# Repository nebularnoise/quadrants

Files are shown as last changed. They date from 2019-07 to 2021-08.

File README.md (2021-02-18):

# Quadrants

Quadrants is a skiff-friendly SMD version of the [Prok Drum Modules](https://www.thonk.co.uk/product-category/manufacturer/prok-modular/).

I love the Prok modules, but the 3-boards sandwich made them too deep to fit in my drum skiff. With this version, the depth is no longer about 40mm, but rather 30mm.

# License

This work is licensed under CC-by-SA 3.0.

It is an adaptation of [Prok-Drums-Hardware](https://github.com/Normalised/Prok-Drums-Hardware), CC-by-SA 3.0 Martin Wood-Mitrovski, a.k.a [@Normalised](https://github.com/Normalised).
Prok Drums is itself an adaptation of [Radio Music](https://github.com/TomWhitwell/RadioMusic), CC-by-SA 3.0 Tom Whitwell, a.k.a. [Music Thing Modular](https://musicthing.co.uk/).

To quote the official Prok Drums page:
> Prok Drums are open hardware, they are a modified version of the Music Thing Modular Radio Music module by Tom Whitwell and have the Creative Commons license CC-BY-SA: Attribution / ShareAlike. If you use any work from this hardware, you should credit Tom Whitwell, and you must republish any changes you make under the same license. The Prok Drums Eagle PCB projects are available under the creative commons license here – [Github Link](https://github.com/Normalised/Prok-Drums-Hardware)

The Quadrants panel uses pictograms derived from the Mutable Instruments Plaits module, licensed under CC-by-SA 3.0. As such, the panel is also licensed under CC-by-SA 3.0.

# Submodule credits
- [4ms/4ms-kicad-lib](https://github.com/4ms/4ms-kicad-lib): Used for some component footprints
  - Thonkiconns
  - Yamaichi SD card holder
  - Alpha 9mm pots
  - rail mounting hole
- [XenGi/teensy.pretty](github.com/XenGi/teensy.pretty): used as inspiration for teensy footprint
- [XenGi/teensy_library](github.com/XenGi/teensy_library): used as inspiration for teensy symbol

# Graphics credit
- Clap icon by [Chathura Kudahetti, LK](https://thenounproject.com/chathura/), released under Public Domain license
- Other pictograms are derived from the Mutable Instruments Plaits module, licensed under CC-by-SA 3.0

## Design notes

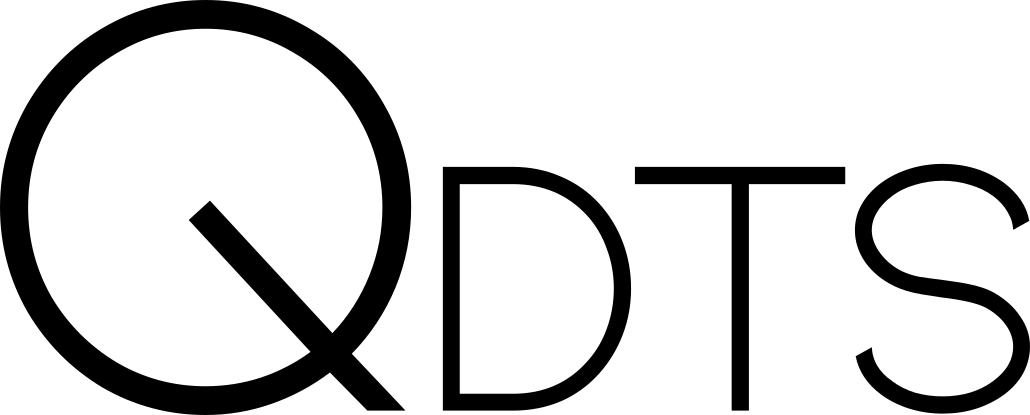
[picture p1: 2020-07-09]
panel_1/qdrnts.png

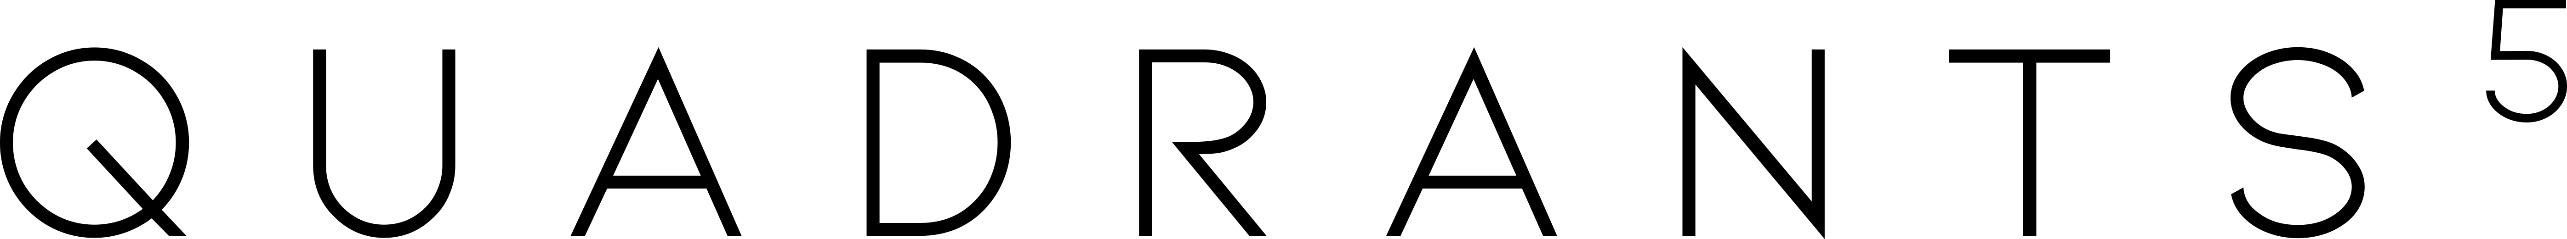
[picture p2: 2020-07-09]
panel_5/panel5.png

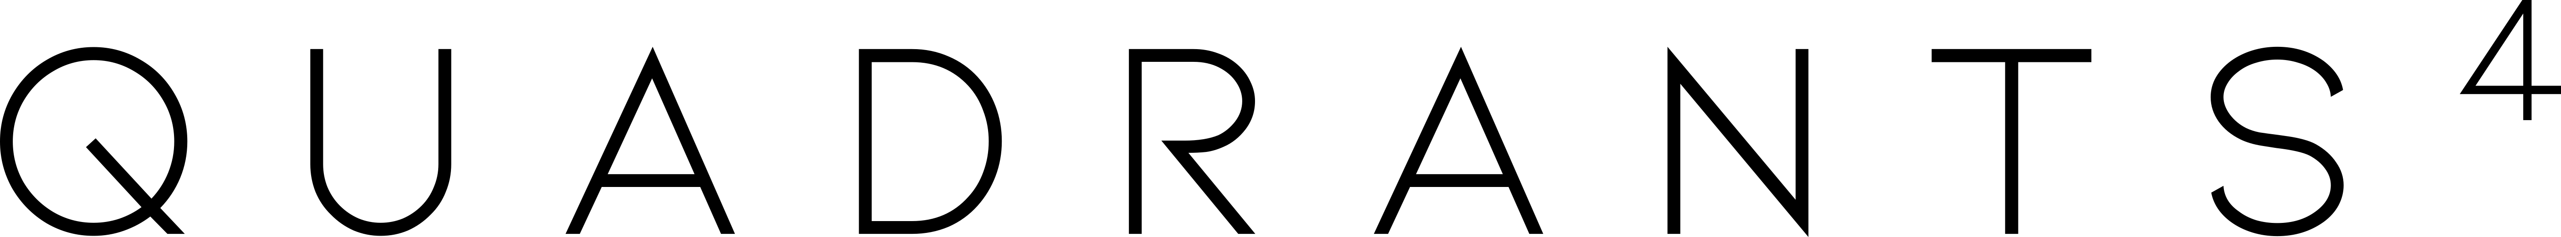
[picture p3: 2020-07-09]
panel_4/panel4.png

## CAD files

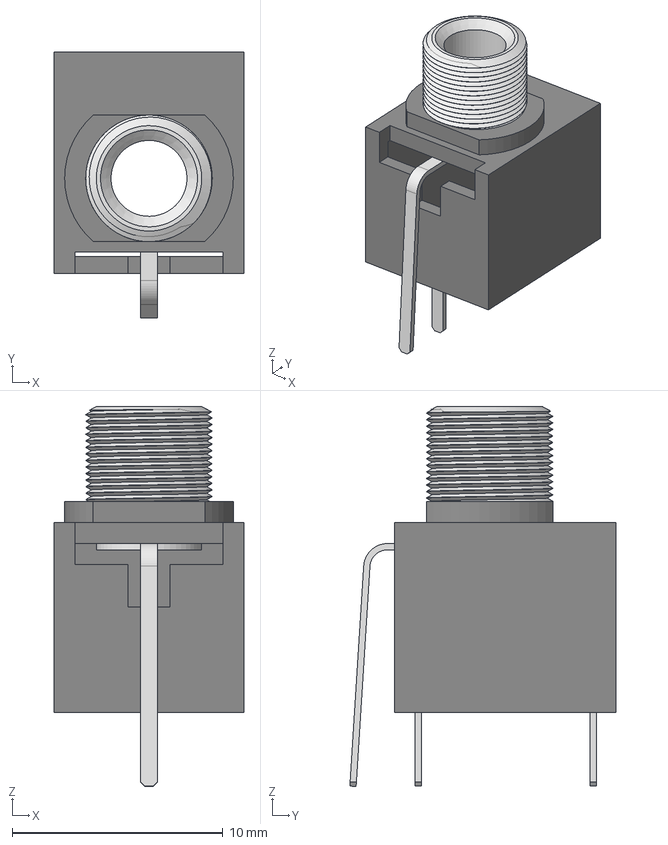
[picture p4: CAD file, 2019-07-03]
3d_models/PJ301M-12 Thonkiconn v0.2.stp
9.00 x 12.6 x 18.0 mm

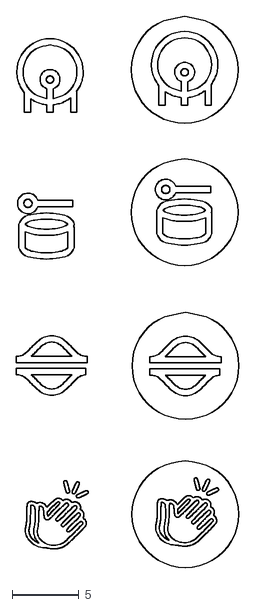
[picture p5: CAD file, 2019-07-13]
images/plaits_drums.dxf
16.7 x 41.3

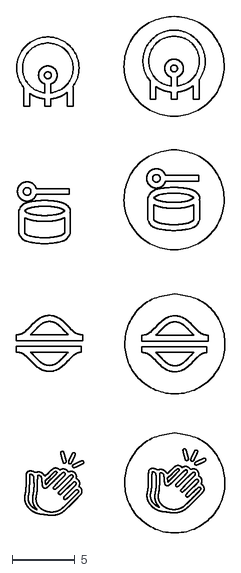
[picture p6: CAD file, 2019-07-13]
images/plaits_drums_r12.dxf
16.7 x 41.3

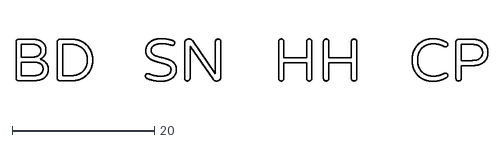
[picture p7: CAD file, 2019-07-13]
images/BD_SN_HH_CP_r12.dxf
66.4 x 6.00

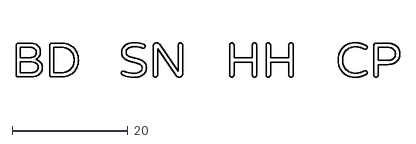
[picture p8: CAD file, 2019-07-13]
images/BD_SN_HH_CP.dxf
66.4 x 6.00

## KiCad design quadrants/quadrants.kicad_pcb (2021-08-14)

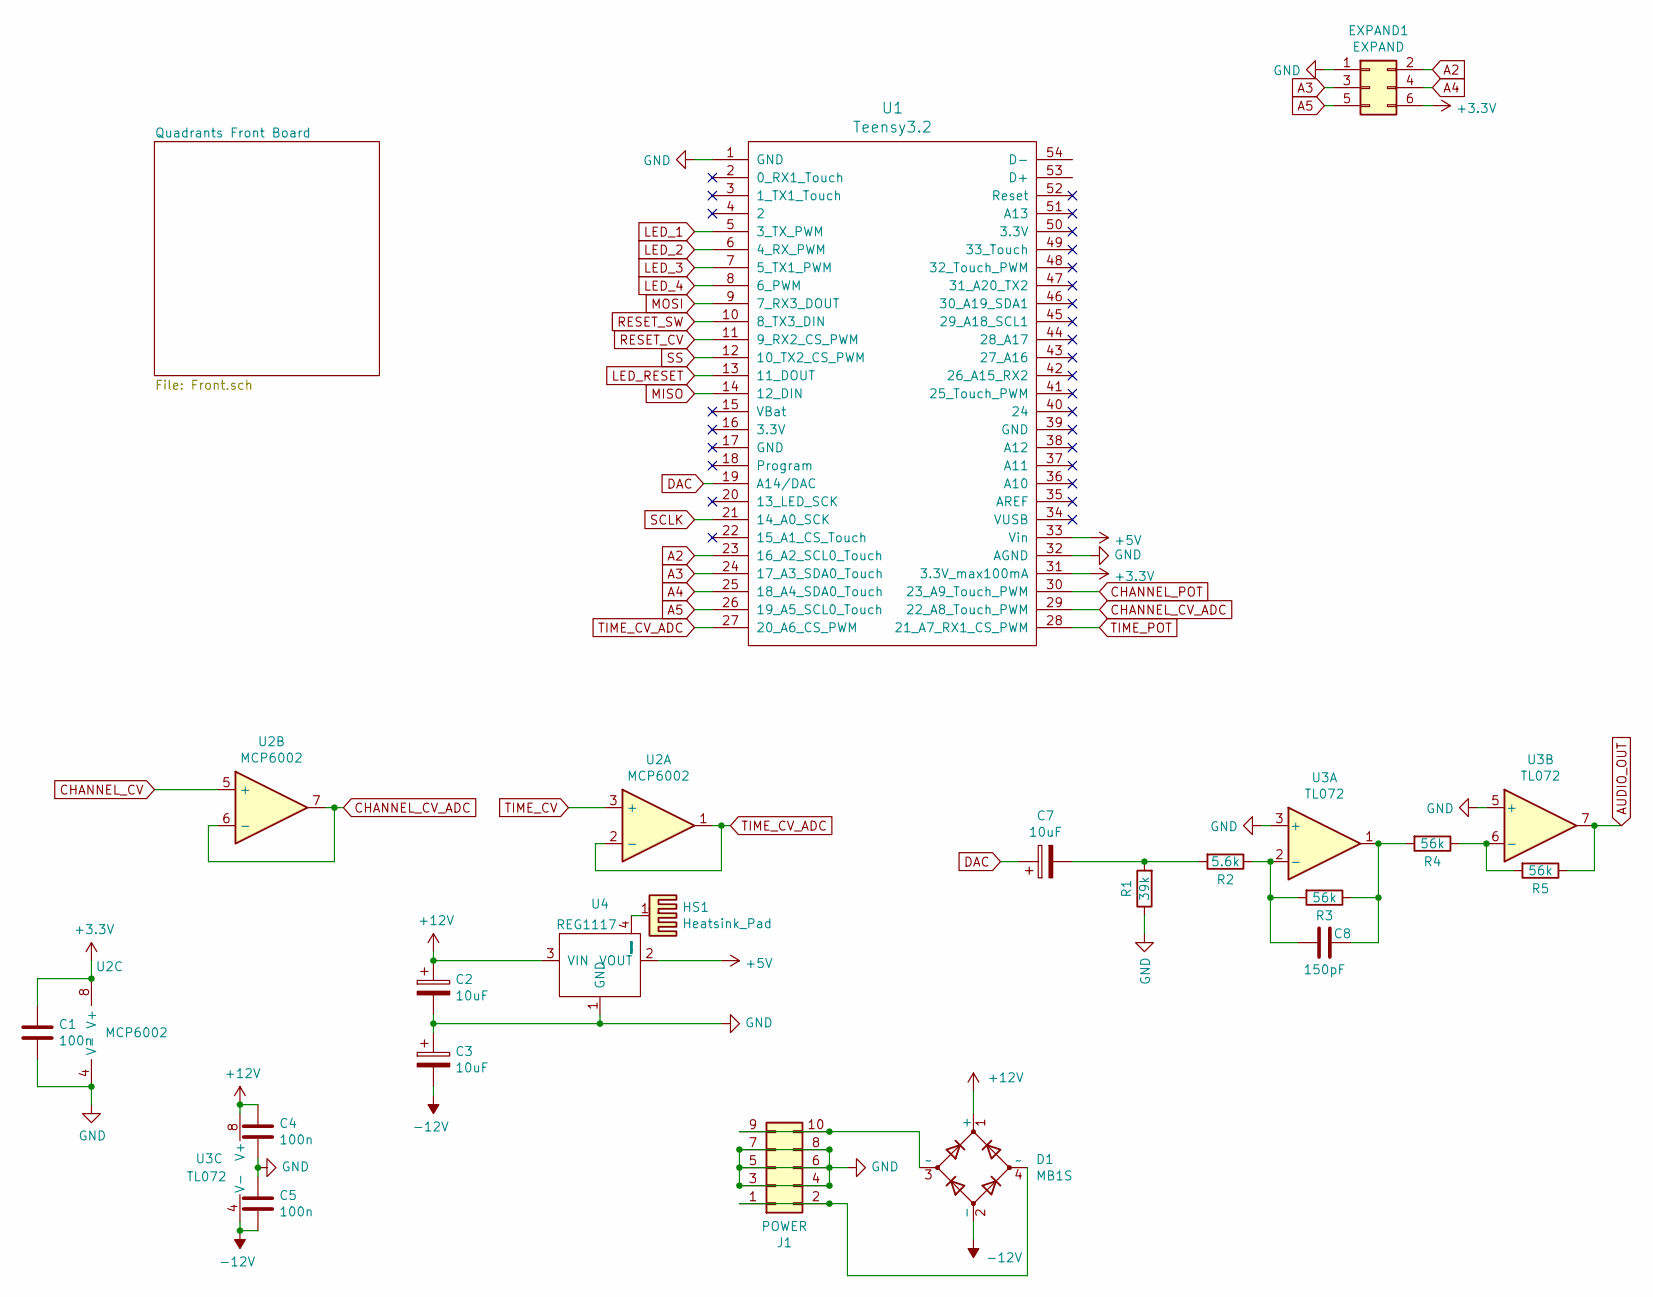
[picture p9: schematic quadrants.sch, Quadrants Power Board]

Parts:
C1, C4, C5: 100n; C_0603_1608Metric
C2, C3, C7: 10uF; CP_Elec_5x5.9
C8: 150pF; C_0603_1608Metric
D1: MB1S; SOIC-4-POWER
EXPAND1: EXPAND; PinHeader_2x03_P2.54mm_Vertical
HS1: Heatsink_Pad
J1: POWER; PinHeader_2x05_P2.54mm_Vertical
R1: 39k; R_0603_1608Metric
R2: 5.6k; R_0603_1608Metric
R3, R4, R5: 56k; R_0603_1608Metric
U1: Teensy3.2; Teensy30_31_32_LC
U2: MCP6002; MSOP-8_3x3mm_P0.65mm
U3: TL072; TSSOP-8_4.4x3mm_P0.65mm
U4: REG1117; SOT-223

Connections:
+5V: U1.33 (Vin), U4.2 (VOUT)
+12V: C2.1, C4.1, D1.1 (+), U3.8 (V+), U4.3 (VIN)
-12V: C3.2, C5.2, D1.2 (-), U3.4 (V-)
A2: EXPAND1.2, U1.23 (16_A2_SCL0_Touch)
A3: EXPAND1.3, U1.24 (17_A3_SDA0_Touch)
A4: EXPAND1.4, U1.25 (18_A4_SDA0_Touch)
A5: EXPAND1.5, U1.26 (19_A5_SCL0_Touch)
AUDIO_OUT: R5.1, U3.7; also elsewhere on the board
CHANNEL_CV: U2.5 (+); also elsewhere on the board
CHANNEL_CV_ADC: U1.29 (22_A8_Touch_PWM), U2.6 (-), U2.7
CHANNEL_POT: U1.30 (23_A9_Touch_PWM); also elsewhere on the board
DAC: C7.1, U1.19 (A14/DAC)
GND: C1.2, C2.2, C3.1, C4.2, C5.1, EXPAND1.1, J1.3, J1.4, J1.5, J1.6, J1.7, J1.8, R1.1, U1.1 (GND), U1.32 (AGND), U2.4 (V-), U3.3 (+), U3.5 (+), U4.1 (GND); also elsewhere on the board
LED_1: U1.5 (3_TX_PWM); also elsewhere on the board
LED_2: U1.6 (4_RX_PWM); also elsewhere on the board
LED_3: U1.7 (5_TX1_PWM); also elsewhere on the board
LED_4: U1.8 (6_PWM); also elsewhere on the board
LED_RESET: U1.13 (11_DOUT); also elsewhere on the board
MISO: U1.14 (12_DIN); also elsewhere on the board
MOSI: U1.9 (7_RX3_DOUT); also elsewhere on the board
unnamed: C7.2, R1.2, R2.2
unnamed: C8.1, R2.1, R3.2, U3.2 (-)
unnamed: C8.2, R3.1, R4.2, U3.1
unnamed: D1.3 (~~), J1.9, J1.10
unnamed: D1.4 (~~), J1.1, J1.2
unnamed: HS1.1, U4.4 (HEATSINK)
unnamed: R4.1, R5.2, U3.6 (-)
RESET_CV: U1.11 (9_RX2_CS_PWM); also elsewhere on the board
RESET_SW: U1.10 (8_TX3_DIN); also elsewhere on the board
SCLK: U1.21 (14_A0_SCK); also elsewhere on the board
SS: U1.12 (10_TX2_CS_PWM); also elsewhere on the board
TIME_CV: U2.3 (+); also elsewhere on the board
TIME_CV_ADC: U1.27 (20_A6_CS_PWM), U2.1, U2.2 (-)
TIME_POT: U1.28 (21_A7_RX1_CS_PWM); also elsewhere on the board

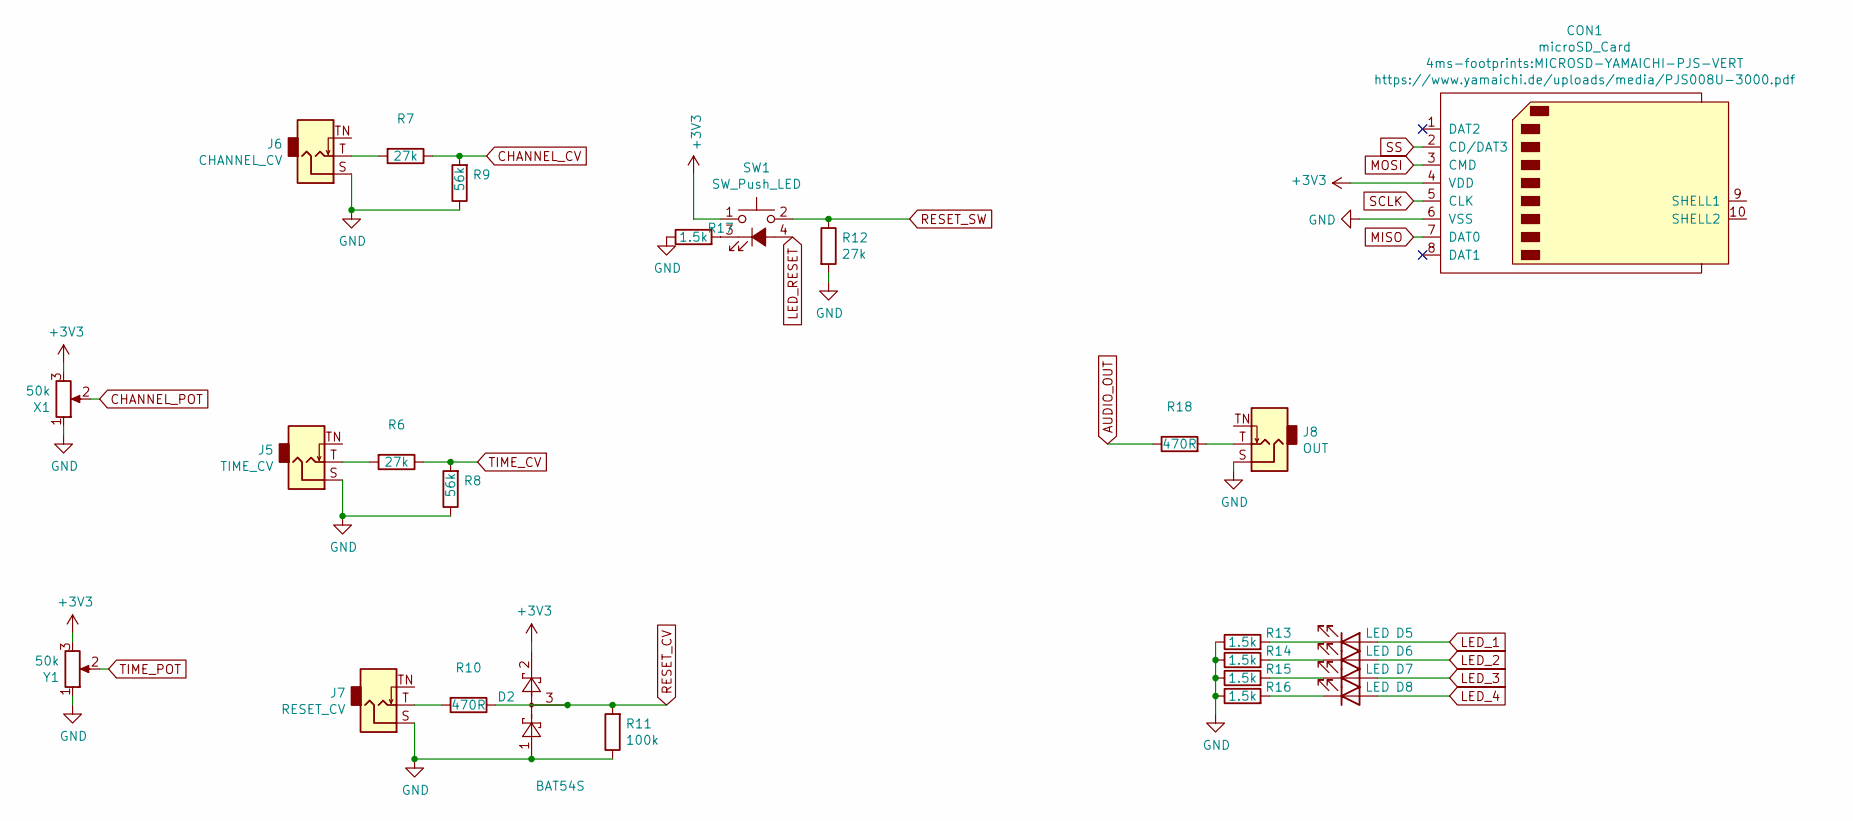
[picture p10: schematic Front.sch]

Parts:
CON1: microSD_Card; MICROSD-YAMAICHI-PJS-VERT
D2: BAT54S; SOT-23
D5, D6, D7, D8: LED; LED-3MM-SQUARE-ANODE
J5: TIME_CV; PJ301M-12
J6: CHANNEL_CV; PJ301M-12
J7: RESET_CV; PJ301M-12
J8: OUT; PJ301M-12
R6, R7, R12: 27k; R_0603_1608Metric
R8, R9: 56k; R_0603_1608Metric
R10, R18: 470R; R_0603_1608Metric
R11: 100k; R_0603_1608Metric
R13, R14, R15, R16, R17: 1.5k; R_0603_1608Metric
SW1: SW_Push_LED; KS01BL
X1: 50k; POT-9MM-ALPHA
Y1: 50k; POT-9MM-ALPHA

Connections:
AUDIO_OUT: R18.1; also elsewhere on the board
CHANNEL_CV: R7.1, R9.2; also elsewhere on the board
CHANNEL_POT: X1.2; also elsewhere on the board
GND: CON1.6 (VSS), D2.1, J5.S, J6.S, J7.S, J8.S, R8.1, R9.1, R11.1, R12.2, R13.1, R14.1, R15.1, R16.1, R17.1, X1.1, Y1.1; also elsewhere on the board
LED_1: D5.2 (A); also elsewhere on the board
LED_2: D6.2 (A); also elsewhere on the board
LED_3: D7.2 (A); also elsewhere on the board
LED_4: D8.2 (A); also elsewhere on the board
LED_RESET: SW1.4 (A); also elsewhere on the board
MISO: CON1.7 (DAT0); also elsewhere on the board
MOSI: CON1.3 (CMD); also elsewhere on the board
unnamed: D5.1 (K), R13.2
unnamed: D6.1 (K), R14.2
unnamed: D7.1 (K), R15.2
unnamed: D8.1 (K), R16.2
unnamed: J5.T, R6.2
unnamed: J6.T, R7.2
unnamed: J7.T, R10.2
unnamed: J8.T, R18.2
unnamed: R17.2, SW1.3 (K)
RESET_CV: D2.3, R10.1, R11.2; also elsewhere on the board
RESET_SW: R12.1, SW1.2; also elsewhere on the board
SCLK: CON1.5 (CLK); also elsewhere on the board
SS: CON1.2 (CD/DAT3); also elsewhere on the board
TIME_CV: R6.1, R8.2; also elsewhere on the board
TIME_POT: Y1.2; also elsewhere on the board

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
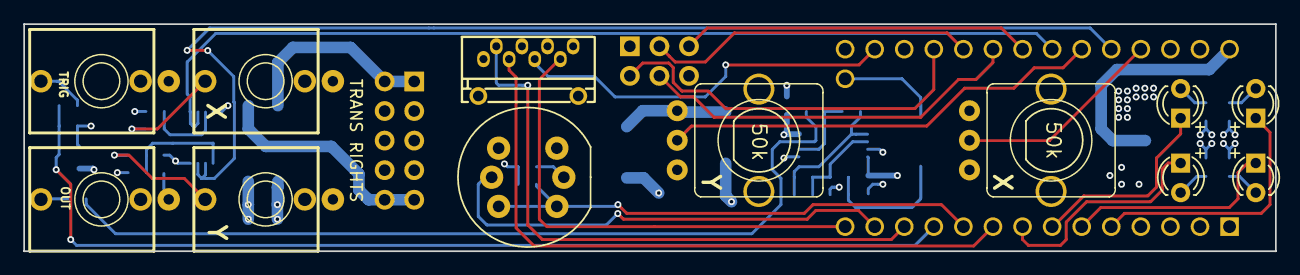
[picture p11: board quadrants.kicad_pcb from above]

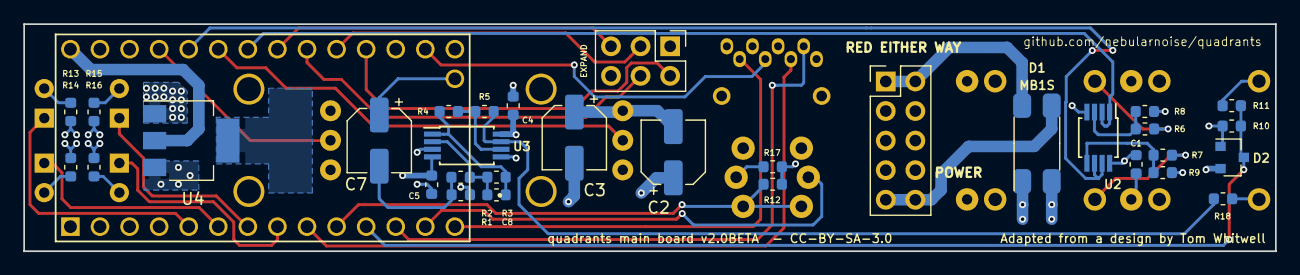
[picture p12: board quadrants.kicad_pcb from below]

Board: 4 copper layers, 107.5 x 19.5 mm, 45 parts (33 on the bottom side), 43 nets.

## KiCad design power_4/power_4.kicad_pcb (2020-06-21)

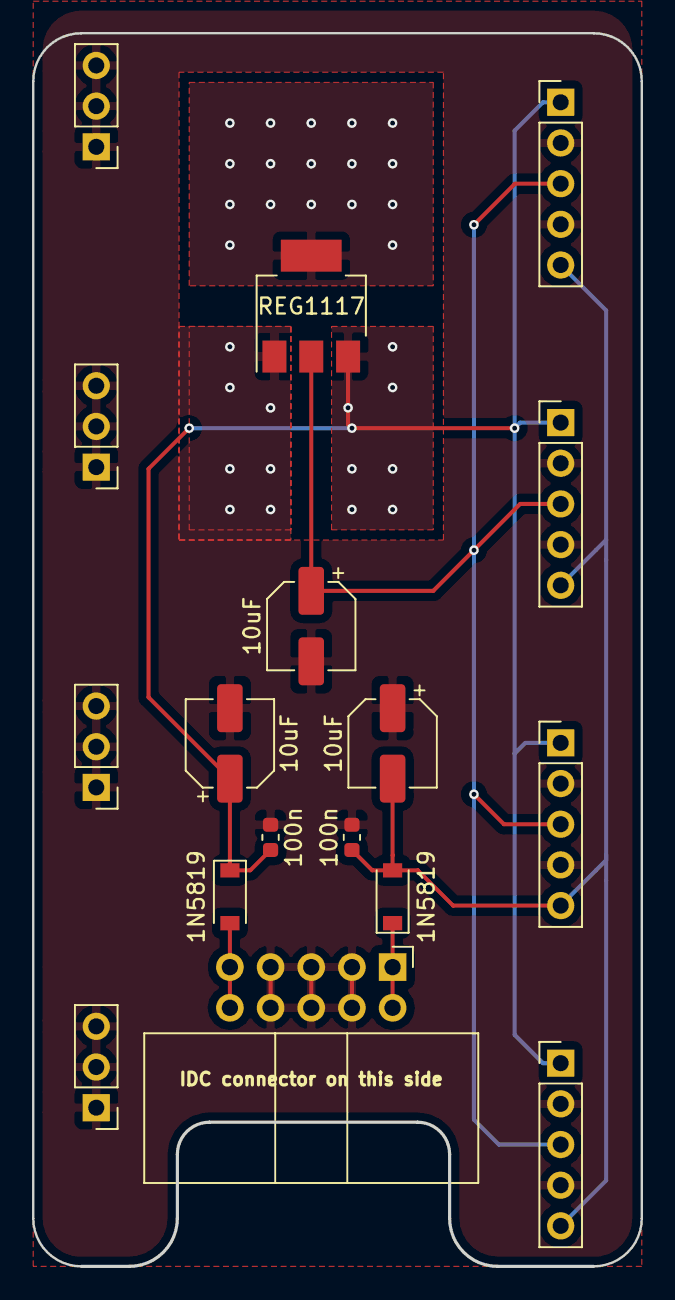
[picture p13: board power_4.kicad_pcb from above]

Board: 2 copper layers, 38.0 x 77.0 mm, 17 parts (0 on the bottom side), 6 nets.

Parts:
C1, C2, C5: 10uF; CP_Elec_5x5.9
C3, C4: 100n; C_0603_1608Metric
D1, D2: 1N5819; D_SOD-123
J1, J3, J6, J9: Conn_01x03_Female; PinHeader_1x03_P2.54mm_Vertical
J2, J4, J5, J8: Conn_01x05_Female; PinHeader_1x05_P2.54mm_Vertical
J7: POWER; IDC-Header_2x05_P2.54mm_Horizontal
U1: REG1117; SOT-223

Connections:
+5V: C5.1, J2.3, J4.3, J5.3, J8.3, U1.2
+12V: C1.1, C3.1, D1.1, J2.1, J4.1, J5.1, J8.1, U1.3
-12V: C2.2, C4.2, D2.2, J2.5, J4.5, J5.5, J8.5
GND: C1.2, C2.1, C3.2, C4.1, C5.2, J1.1, J1.2, J1.3, J2.2, J2.4, J3.1, J3.2, J3.3, J4.2, J4.4, J5.2, J5.4, J6.1, J6.2, J6.3, J7.3, J7.4, J7.5, J7.6, J7.7, J7.8, J8.2, J8.4, J9.1, J9.2, J9.3, U1.1
unnamed: D1.2, J7.9, J7.10
unnamed: D2.1, J7.1, J7.2

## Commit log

2019-06-30 :construction: first draft of kicad smd two board version
    [Front.sch, prok_smd.kicad_pcb, prok_smd.sch]
2019-06-30 :construction: Aligned UI elements to panel specs
    [prok_smd.kicad_pcb]
2019-07-01 :construction: Locked headers and added mousebites
    [Front.sch, prok_smd.kicad_pcb, prok_smd.sch]
2019-07-02 :construction: first draft routing
    [Front.sch, prok_smd.kicad_pcb, prok_smd.sch]
2019-07-02 :sparkles: finished first draft routing. Matched lengths for SD card traces
    [prok_smd.kicad_pcb]
2019-07-02 :bug: fixed backwards pots
    [Front.sch, prok_smd.kicad_pcb]
2019-07-02 :sparkles: Fixed switch led
    [Front.sch, prok_smd.kicad_pcb]
2019-07-03 :recycle: silkscreen cleanup
    [prok_smd.kicad_pcb]
2019-07-03 :recycle: traces cleanup
    [prok_smd.kicad_pcb]
2019-07-03 :see_no_evil: :fire: delete and ignore backup files
    [PROK drum_B.brd, PROK drum_B.sch, PROK drum_F.brd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]
2019-07-03 :recycle: reorganize files
    [PJ301M-12 Thonkiconn v0.2.stp, prok_smd.kicad_pcb]
2019-07-03 :sparkles: :construction: first draft v2 board
    [Front.sch, prok_smd.kicad_pcb, prok_smd.sch]
2019-07-03 :sparkles: :construction: first draft routing v2
    [prok_smd.kicad_pcb]
2019-07-05 :sparkles: Silkscreen cleanup
    [prok_smd.kicad_pcb]
2019-07-12 :sparkles: Clarify silkscreen LEDs, thicken power traces
    [prok_smd.kicad_pcb]
2019-07-12 :sparkles: Added multi_power board (powers 4 proks)
    [multi_power.kicad_pcb, multi_power.sch]
2019-07-13 :sparkles: Panel (single)
    [panel_single.kicad_pcb, prok_logo.dxf, prok_logo_r12.dxf]
2019-07-13 :sparkles: Panel (x4 kit)
    Valera round for the font
    [BD_SN_HH_CP.dxf, BD_SN_HH_CP_r12.dxf, panel_multi.kicad_pcb]
2019-07-13 :lipstick: Panel (x4) changed graphics (plaits style) & changed name ;)
    [panel_multi.kicad_pcb, plaits_drums.dxf, plaits_drums_r12.dxf]
2019-07-16 :lipstick: :sparkles: Gold (soldermask hole) instead of silkscreen
    [panel_multi.kicad_pcb, panel_multi.sch, panel_single.kicad_pcb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]
2019-08-09 :bug: Fix LEDs misplacement
    Led pads were placed 2.5mm lower than they should have.
    [prok_smd.kicad_pcb]
2020-06-21 :recycle: redid power pcb single
    [Front.sch, multi_power.kicad_pcb, prok_smd.kicad_pcb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]
2020-06-24 :recycle: rerouted all pcb
    same
    same
    [Front.sch, prok_smd.kicad_pcb, prok_smd.sch]
2020-06-24 :zap: Added Either way power and more rugged fixations
    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
    [prok_smd.kicad_pcb, prok_smd.sch]
2020-06-24 :construction: Add some caps to smoothe PWM
    [Front.sch, prok_smd.kicad_pcb]
2020-06-28 :recycle: Redid routing
    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
    [Front.sch, prok_smd.kicad_pcb, prok_smd.sch]
2020-06-30 :truck: :lipstick: Move CV circuitry back, and clean PCB
    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
    [prok_smd.kicad_pcb]
2020-07-01 :truck: Rename
    [quadrants.kicad_pcb, quadrants.sch]
2020-07-01 :recycle: :truck: Move stuff around, organise
    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
    [BD_SN_HH_CP.dxf, BD_SN_HH_CP_r12.dxf, Front.sch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]
2020-07-08 :lipstick: Add BLM logo
    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
    [quadrants.kicad_pcb]
2020-07-08 :bug: Fix panel single (better clearance for LEDs & switch)
    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
    [panel_single.kicad_pcb, panel_single.sch]
2020-07-08 :bug: redid the panel 4 from new panel 1
    [panel_4.kicad_pcb, panel_4.sch]
2020-07-08 :sparkles: panel 5 !!
    [panel_5.kicad_pcb]
2020-07-09 :sparkles: update panels
    [panel_4.kicad_pcb, panel_5.kicad_pcb, panel_single.kicad_pcb]
2021-02-19 :construction: prepare 4 layer board layout
    [Front.sch, quadrants.kicad_pcb, quadrants.sch]
2021-02-20 :construction: first draft at 4 layer layout
    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
    [Front.sch, quadrants.kicad_pcb, quadrants.sch]
2021-02-20 :recycle: Clean up silkscreen
    [quadrants.kicad_pcb]
2021-02-22 :recycle: Use THT power header !
    [quadrants.kicad_pcb, quadrants.sch]
2021-02-23 :bug: Fix button footprint
    [quadrants.kicad_pcb]
2021-08-14 :fire: Remove a few obsolete dimensions (iirc)
    [quadrants.kicad_pcb]

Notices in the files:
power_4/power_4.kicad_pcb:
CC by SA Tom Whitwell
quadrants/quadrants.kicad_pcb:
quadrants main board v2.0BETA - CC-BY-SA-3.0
